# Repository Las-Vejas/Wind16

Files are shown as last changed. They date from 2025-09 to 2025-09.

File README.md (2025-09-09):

# Wind16
A 4x4 macropad, with backlit keys and a fully square design.

## Components

The macropad contains 16 keys, each backlit with an SK6812mini-e led. It is controlled by a Seeed XIAO RP2040 microcontroller using either kmk or qmk software.
The switches will be Gateron Milky Yellows as they feel magnificent. On them there will be white keycaps on which I will make vynil stickers for when I decide on the actions that the keys will be doing.

A lot of people on the HackClub Slack have been against my design, and how I have placed the Xiao. I myself think its a great design choice, that won’t interfere with any other component because, in theory with pin headers commonly being 2 mm tall, I should have enough clearance to fit my components on the top and bottom part of the pcb with just enough to spare so that the RP2040 wouldn’t be touching anything.

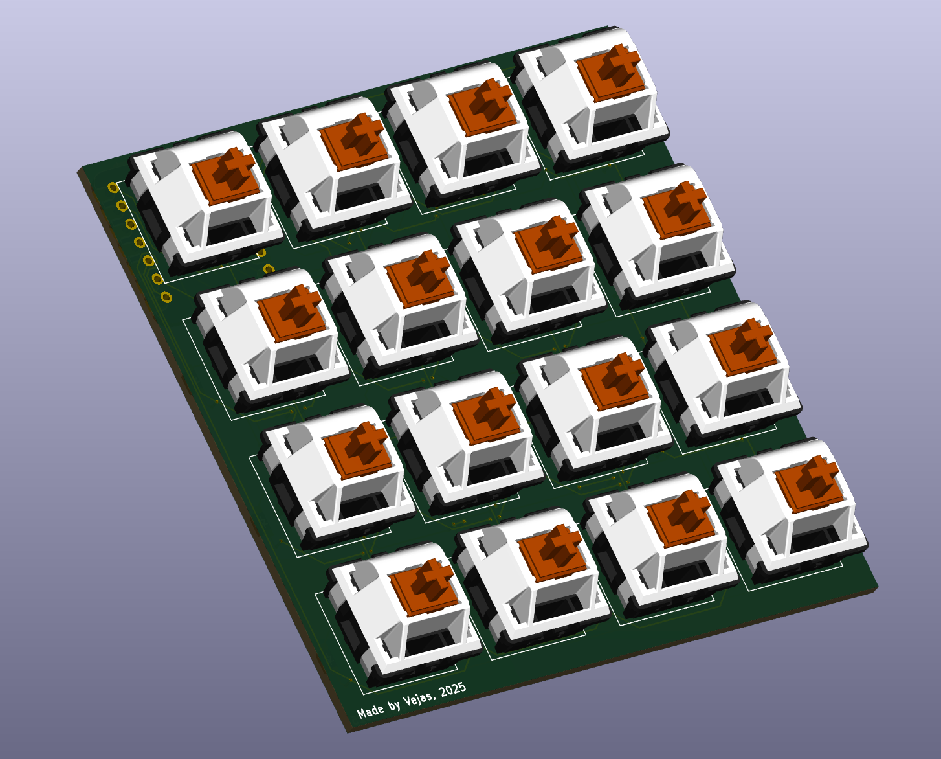
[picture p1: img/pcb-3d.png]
<br>

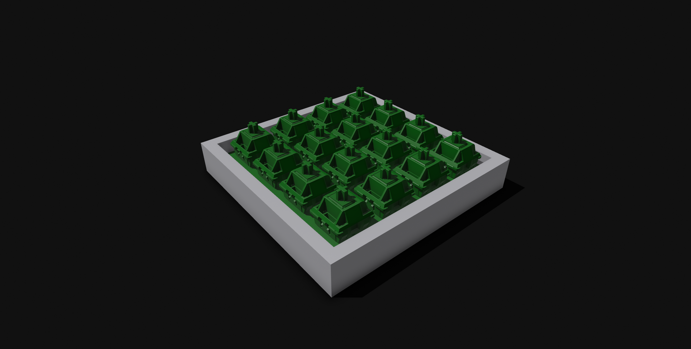
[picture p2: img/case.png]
<br>

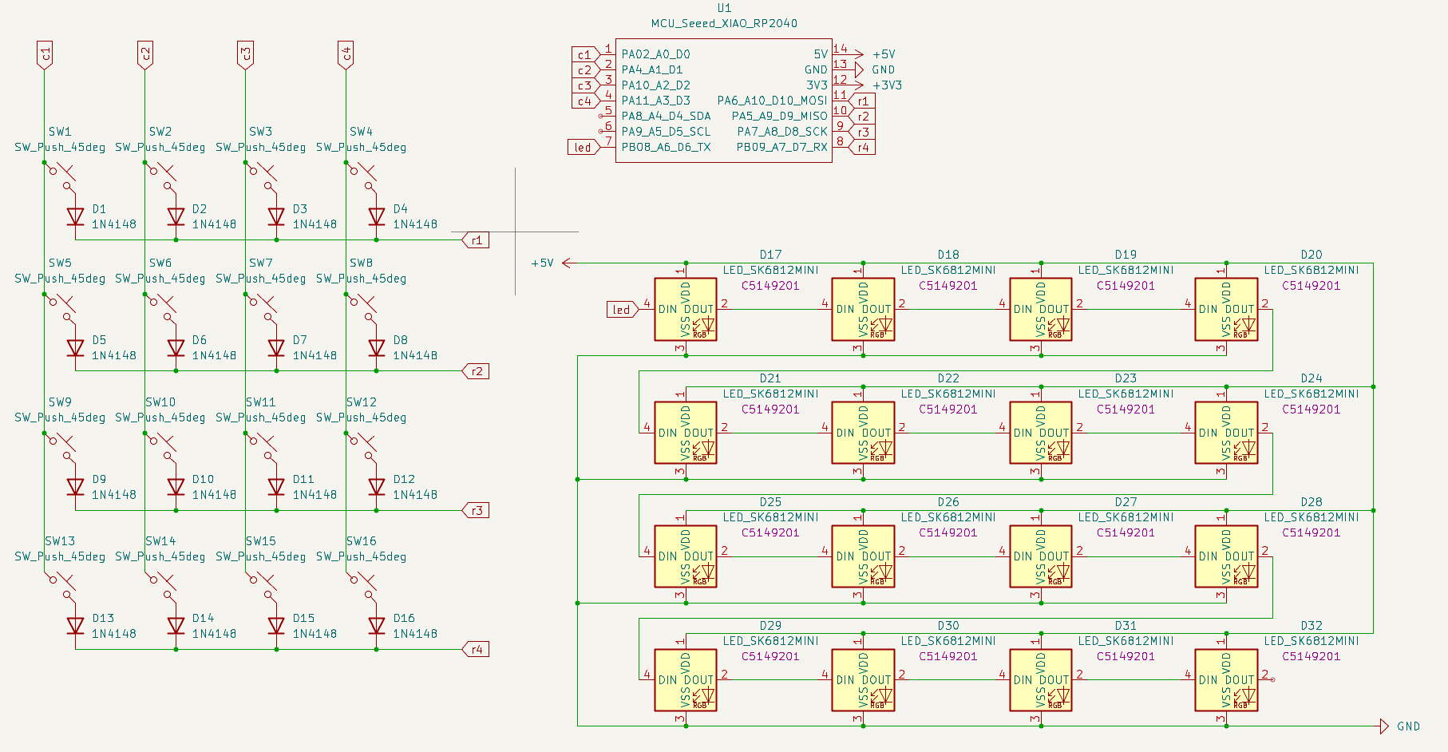
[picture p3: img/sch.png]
<br>

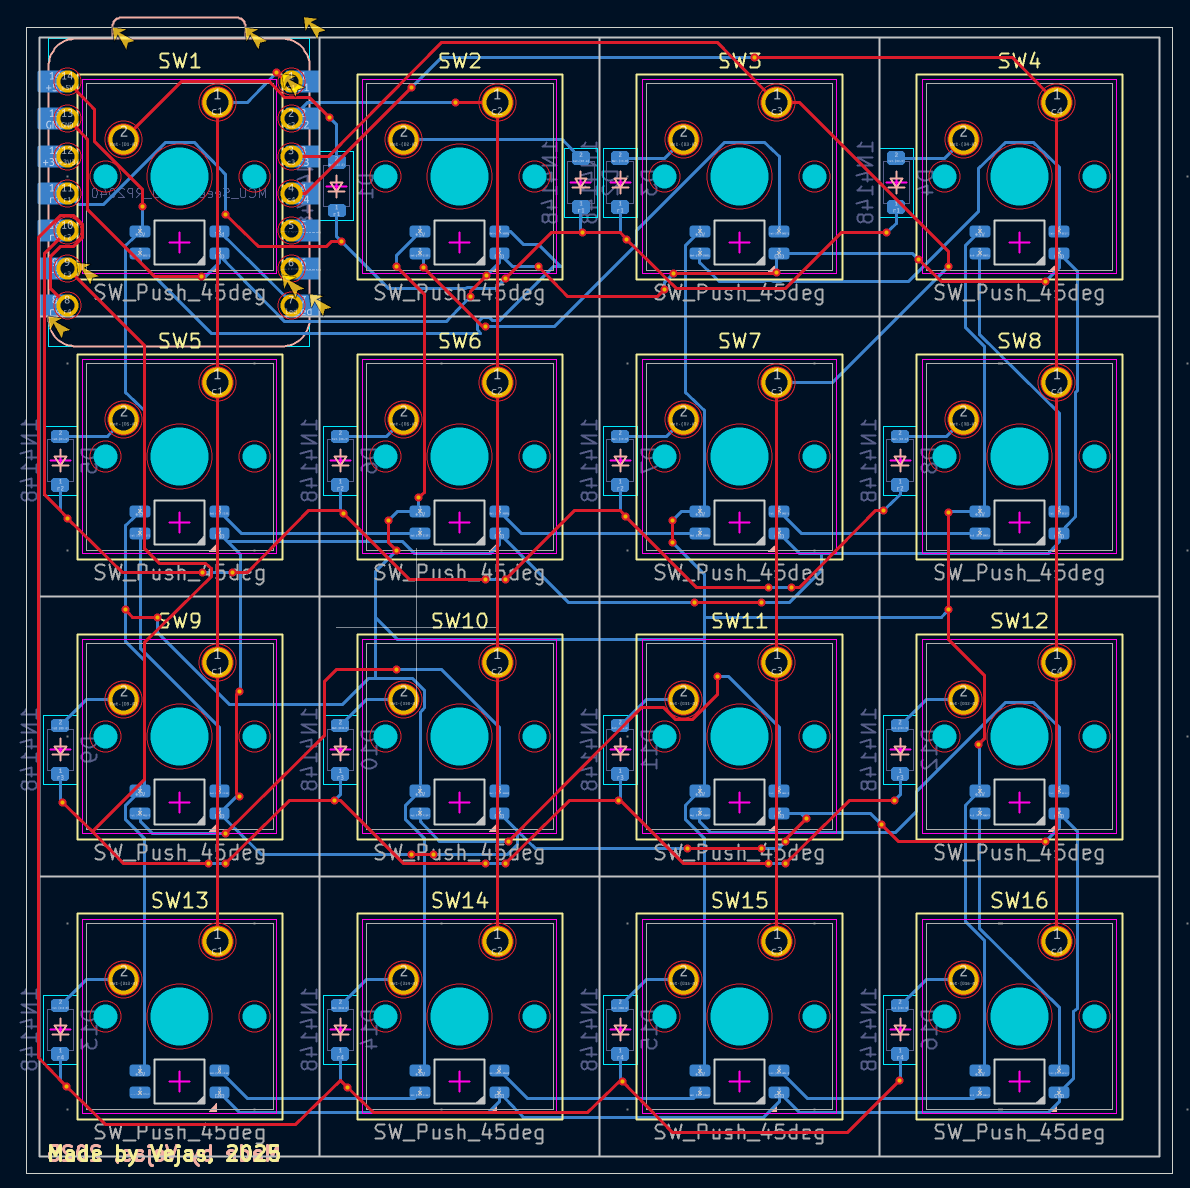
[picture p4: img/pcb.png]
<br>

## BOM

| **Quantity** | **Item** | **Cost** | **Link** |
| --- | --- | --- | --- |
| 16 | Gateron Milky Yellow Switches | $8.32 | [Link](https://fr.aliexpress.com/item/1005006425450443.html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) |
| 16 | Diodes SOD-123 | $1.56 | [Link](https://fr.aliexpress.com/item/1005001994794541.html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) |
| 16 | SK6812mini-e Leds | $3.33 | [Link](https://fr.aliexpress.com/item/1005003056797785.html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) |
| 1 | Seeed Xiao RP2040 | $8.75 | [Link](https://fr.aliexpress.com/item/1005003682505451.html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) |
| 16 | See-through keycaps | $8.28 | [Link](https://fr.aliexpress.com/item/1005002976015114.html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) |
| 1 | 3D printed case | N/A | N/A  | 
| 5 | M2 6mm Screws | $1.70 | [Link](https://www.aliexpress.com/item/1005004531602992.html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) | | 5 | M2 8mm Standoffs | $3.99 | [Link](https://www.aliexpress.com/item/32974970926.html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) |
| 5 | M2 8mm Standoffs | $3.30 | [Link](https://www.aliexpress.com/item/32974970926.html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) |
| 5 | Rubber Bumpers (feet) | $4.01 | [Link](https://fr.aliexpress.com/item/1005006259472984.html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) |

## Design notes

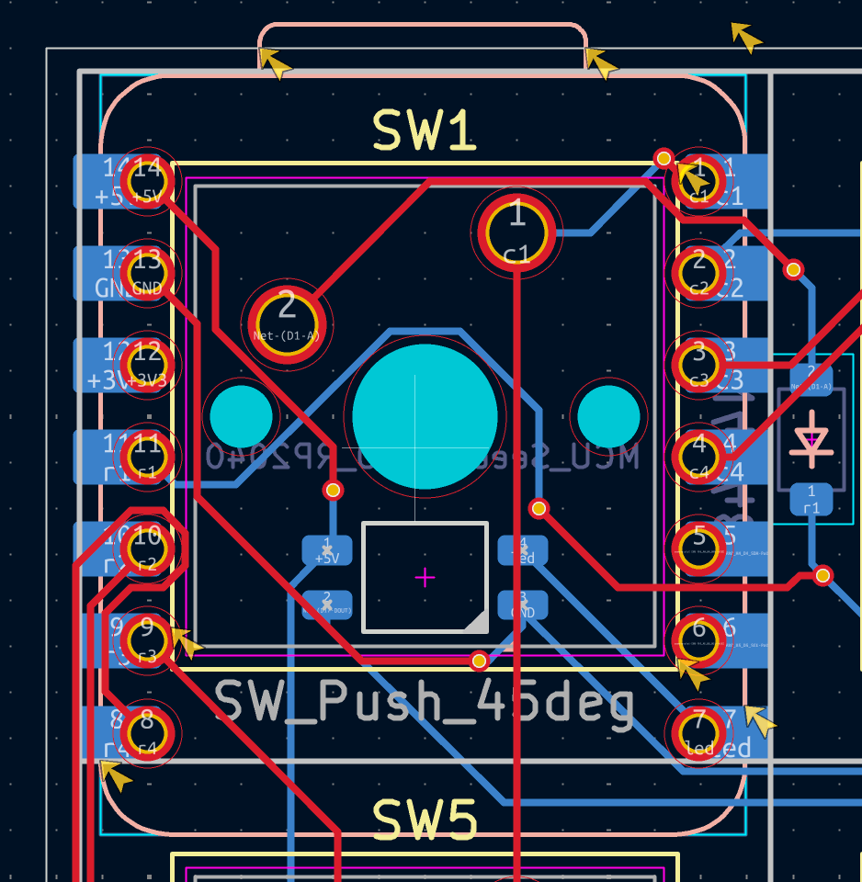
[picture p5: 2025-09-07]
img/xiao.png

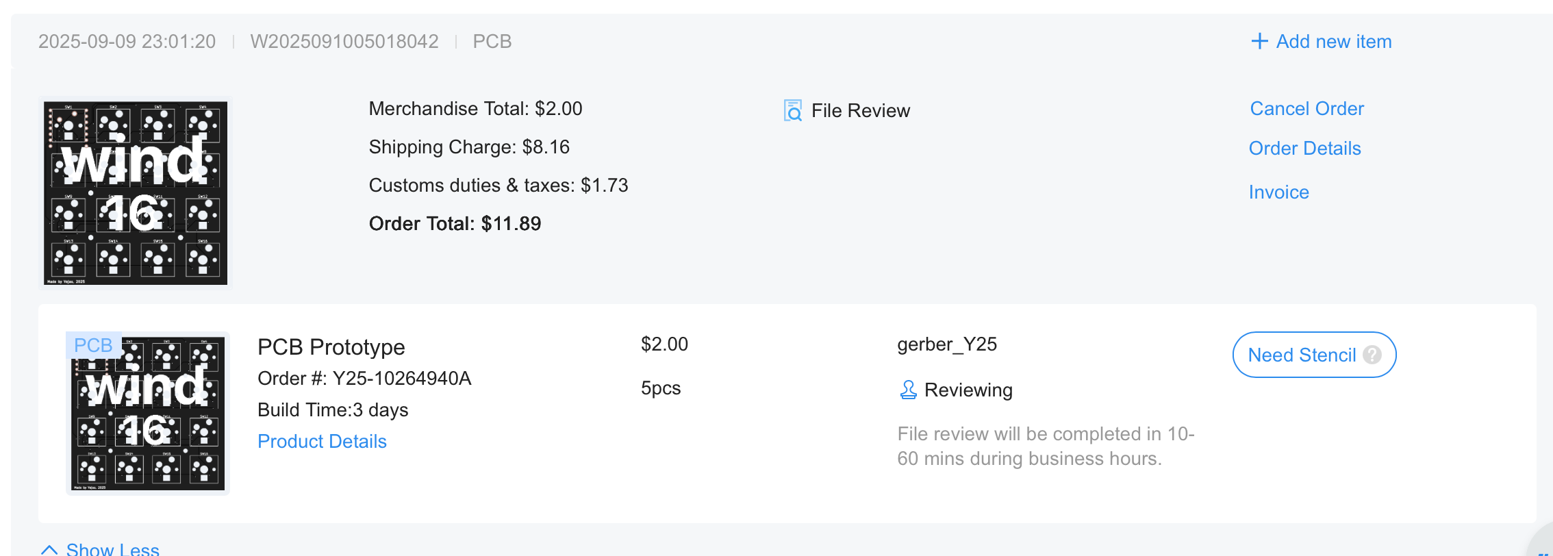
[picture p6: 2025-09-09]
jlccart.png

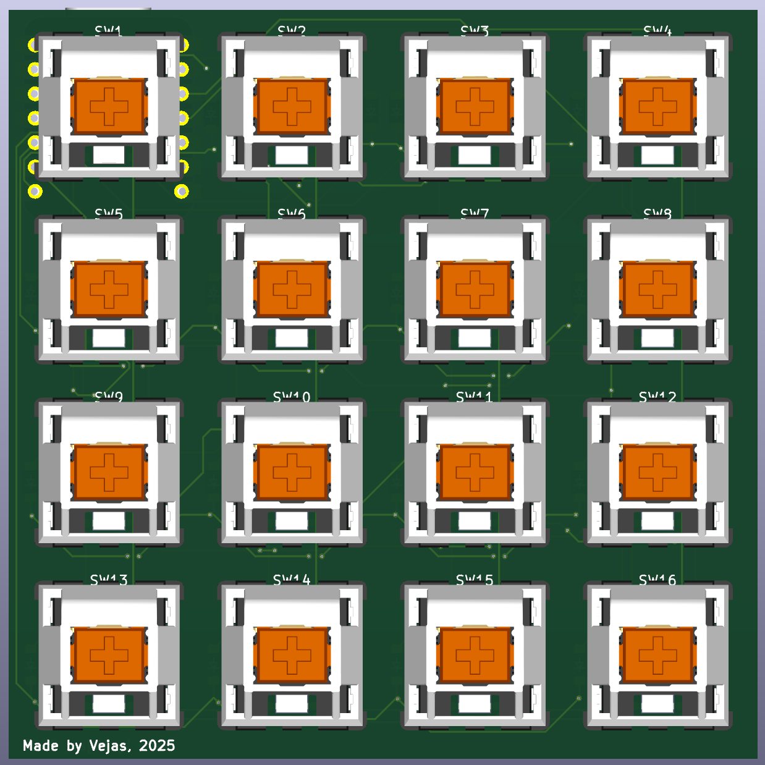
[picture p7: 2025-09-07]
img/pcb-topdown.png

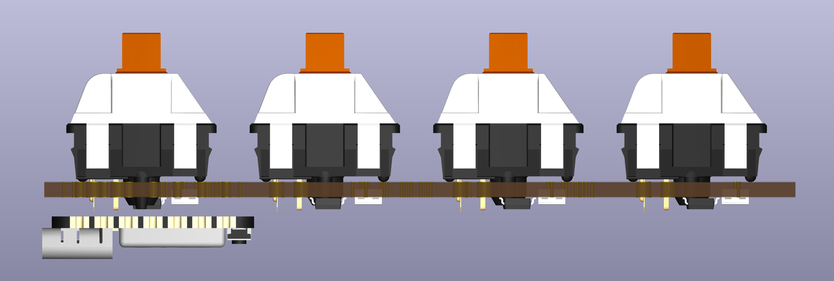
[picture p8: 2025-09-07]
img/SCR-20250907-kzoe.png

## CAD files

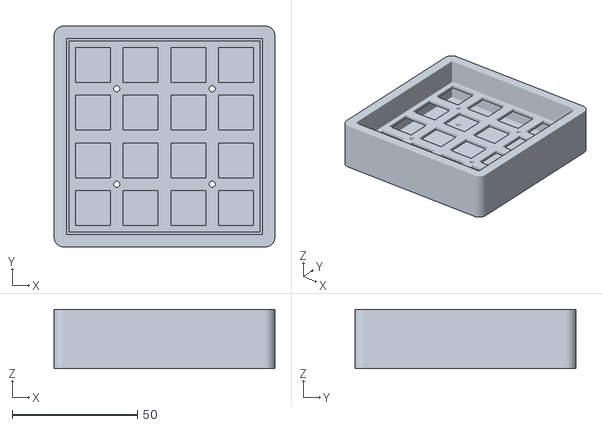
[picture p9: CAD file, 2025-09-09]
3d/case-new.stl
88.2 x 88.2 x 23.6

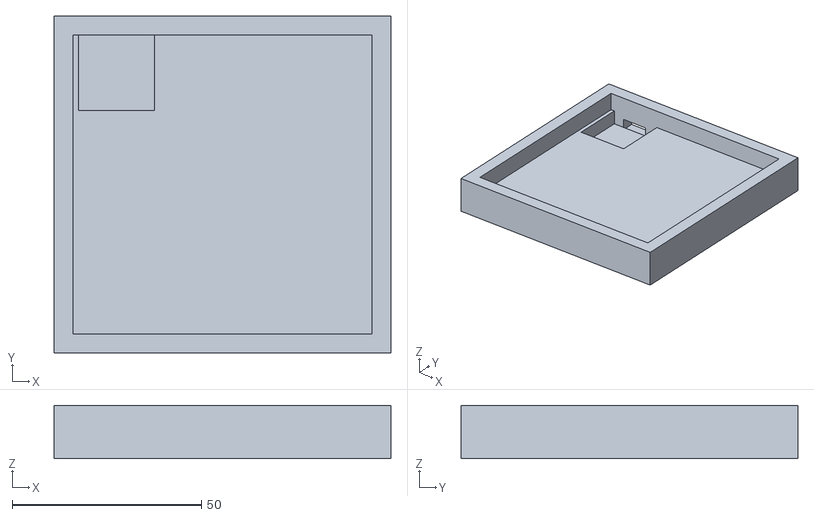
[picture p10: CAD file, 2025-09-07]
3d/wind16-case.stl
89.0 x 89.0 x 14.0

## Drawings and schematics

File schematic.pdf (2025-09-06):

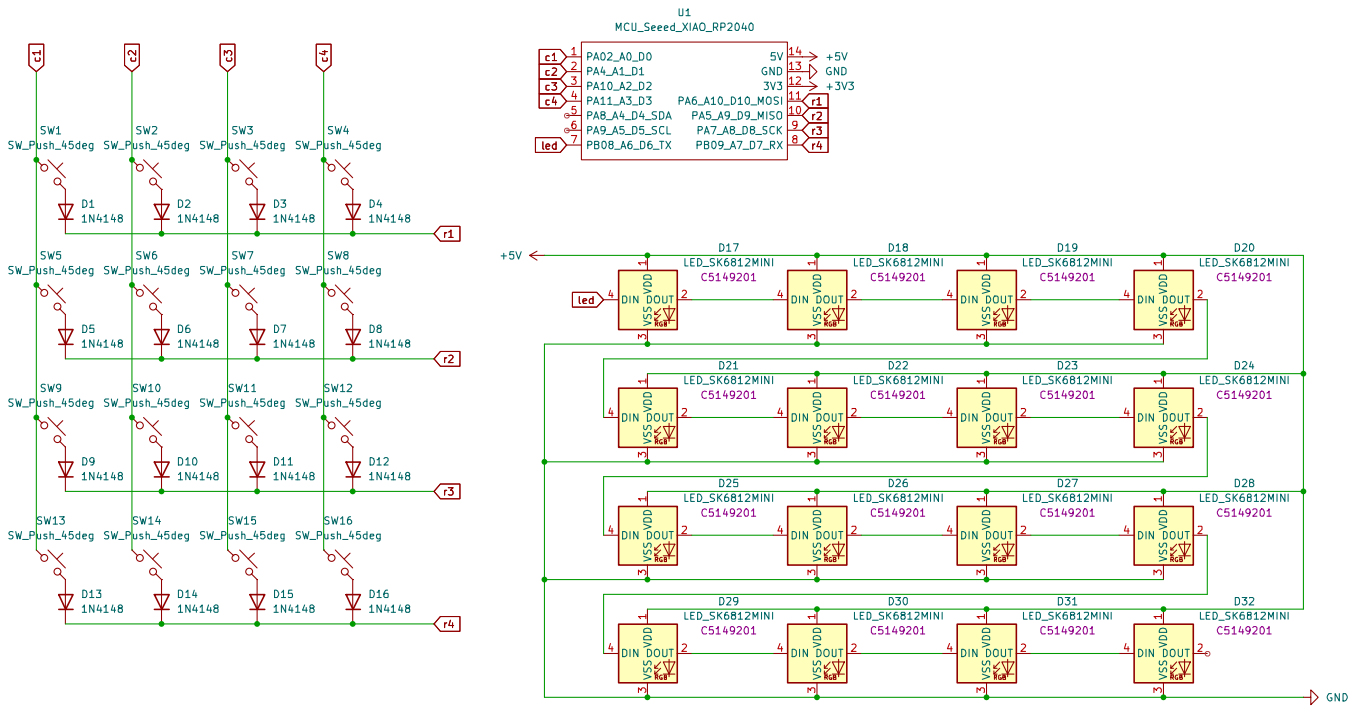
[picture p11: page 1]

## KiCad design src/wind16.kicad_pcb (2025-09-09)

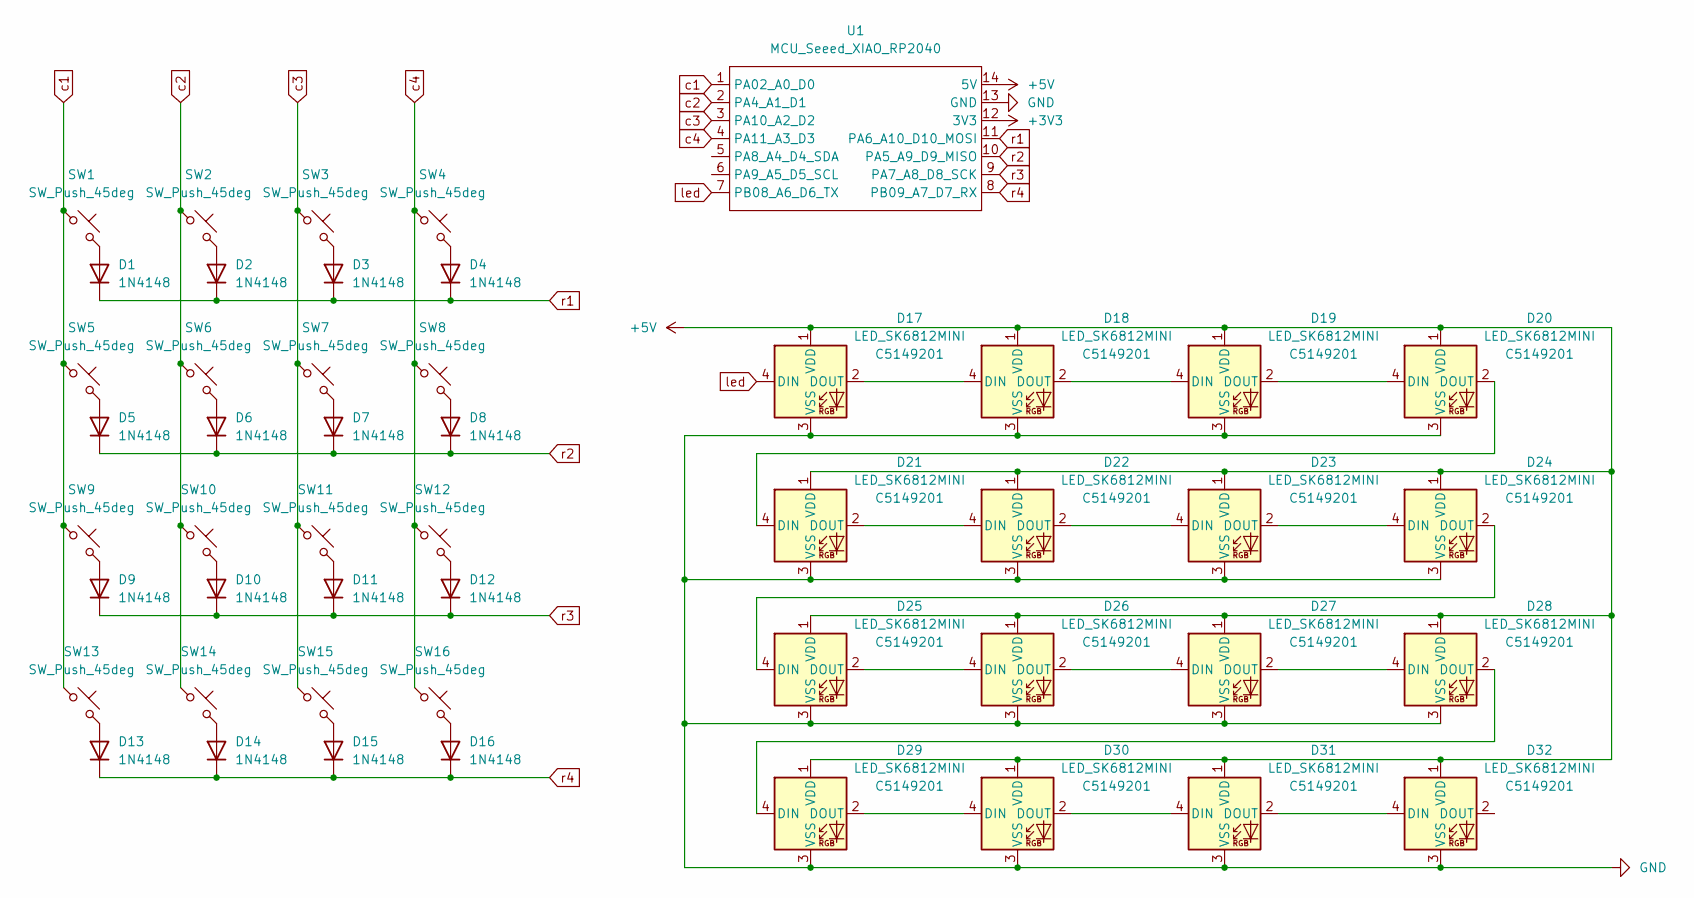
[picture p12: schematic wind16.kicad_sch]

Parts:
D1, D2, D3, D4, D5, D6, D7, D8, D9, D10, D11, D12, D13, D14, D15, D16: 1N4148; Diode_SOD-123
D17, D18, D19, D20, D21, D22, D23, D24, D25, D26, D27, D28, D29, D30, D31, D32: LED_SK6812MINI; LCSC C5149201
SW1: SW_Push_45deg; SW_Cherry_MX_1.00u_PCB
SW2, SW3, SW4, SW5, SW6, SW7, SW8, SW9, SW10, SW11, SW12, SW13, SW14, SW15, SW16: SW_Push_45deg; Hotswap_MX_1.00u
U1: MCU_Seeed_XIAO_RP2040; XIAO-RP2040-DIP

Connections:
+3V3: U1.12 (3V3)
+5V: D17.1 (VDD), D18.1 (VDD), D19.1 (VDD), D20.1 (VDD), D21.1 (VDD), D22.1 (VDD), D23.1 (VDD), D24.1 (VDD), D25.1 (VDD), D26.1 (VDD), D27.1 (VDD), D28.1 (VDD), D29.1 (VDD), D30.1 (VDD), D31.1 (VDD), D32.1 (VDD), U1.14 (5V)
GND: D17.3 (VSS), D18.3 (VSS), D19.3 (VSS), D20.3 (VSS), D21.3 (VSS), D22.3 (VSS), D23.3 (VSS), D24.3 (VSS), D25.3 (VSS), D26.3 (VSS), D27.3 (VSS), D28.3 (VSS), D29.3 (VSS), D30.3 (VSS), D31.3 (VSS), D32.3 (VSS), U1.13 (GND)
unnamed: D1.2 (A), SW1.2
unnamed: D2.2 (A), SW2.2
unnamed: D3.2 (A), SW3.2
unnamed: D4.2 (A), SW4.2
unnamed: D5.2 (A), SW5.2
unnamed: D6.2 (A), SW6.2
unnamed: D7.2 (A), SW7.2
unnamed: D8.2 (A), SW8.2
unnamed: D9.2 (A), SW9.2
unnamed: D10.2 (A), SW10.2
unnamed: D11.2 (A), SW11.2
unnamed: D12.2 (A), SW12.2
unnamed: D13.2 (A), SW13.2
unnamed: D14.2 (A), SW14.2
unnamed: D15.2 (A), SW15.2
unnamed: D16.2 (A), SW16.2
unnamed: D17.2 (DOUT), D18.4 (DIN)
unnamed: D18.2 (DOUT), D19.4 (DIN)
unnamed: D19.2 (DOUT), D20.4 (DIN)
unnamed: D20.2 (DOUT), D21.4 (DIN)
unnamed: D21.2 (DOUT), D22.4 (DIN)
unnamed: D22.2 (DOUT), D23.4 (DIN)
unnamed: D23.2 (DOUT), D24.4 (DIN)
unnamed: D24.2 (DOUT), D25.4 (DIN)
unnamed: D25.2 (DOUT), D26.4 (DIN)
unnamed: D26.2 (DOUT), D27.4 (DIN)
unnamed: D27.2 (DOUT), D28.4 (DIN)
unnamed: D28.2 (DOUT), D29.4 (DIN)
unnamed: D29.2 (DOUT), D30.4 (DIN)
unnamed: D30.2 (DOUT), D31.4 (DIN)
unnamed: D31.2 (DOUT), D32.4 (DIN)
c1: SW1.1, SW5.1, SW9.1, SW13.1, U1.1 (PA02_A0_D0)
c2: SW2.1, SW6.1, SW10.1, SW14.1, U1.2 (PA4_A1_D1)
c3: SW3.1, SW7.1, SW11.1, SW15.1, U1.3 (PA10_A2_D2)
c4: SW4.1, SW8.1, SW12.1, SW16.1, U1.4 (PA11_A3_D3)
led: D17.4 (DIN), U1.7 (PB08_A6_D6_TX)
r1: D1.1 (K), D2.1 (K), D3.1 (K), D4.1 (K), U1.11 (PA6_A10_D10_MOSI)
r2: D5.1 (K), D6.1 (K), D7.1 (K), D8.1 (K), U1.10 (PA5_A9_D9_MISO)
r3: D9.1 (K), D10.1 (K), D11.1 (K), D12.1 (K), U1.9 (PA7_A8_D8_SCK)
r4: D13.1 (K), D14.1 (K), D15.1 (K), D16.1 (K), U1.8 (PB09_A7_D7_RX)

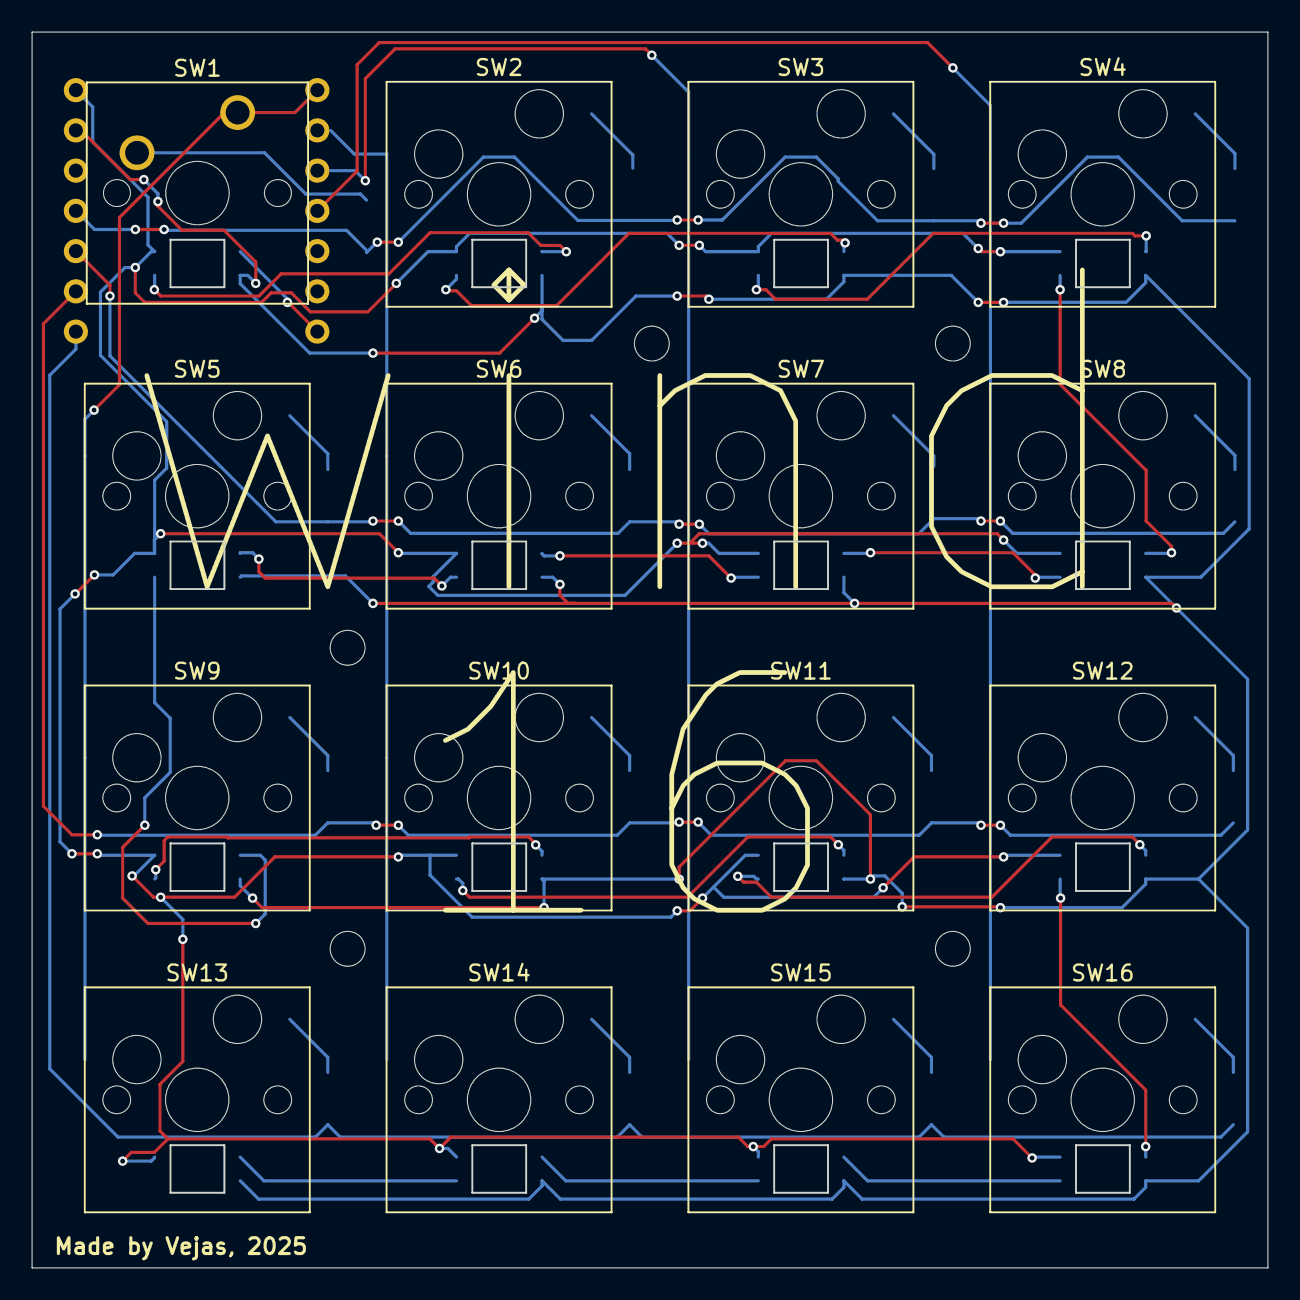
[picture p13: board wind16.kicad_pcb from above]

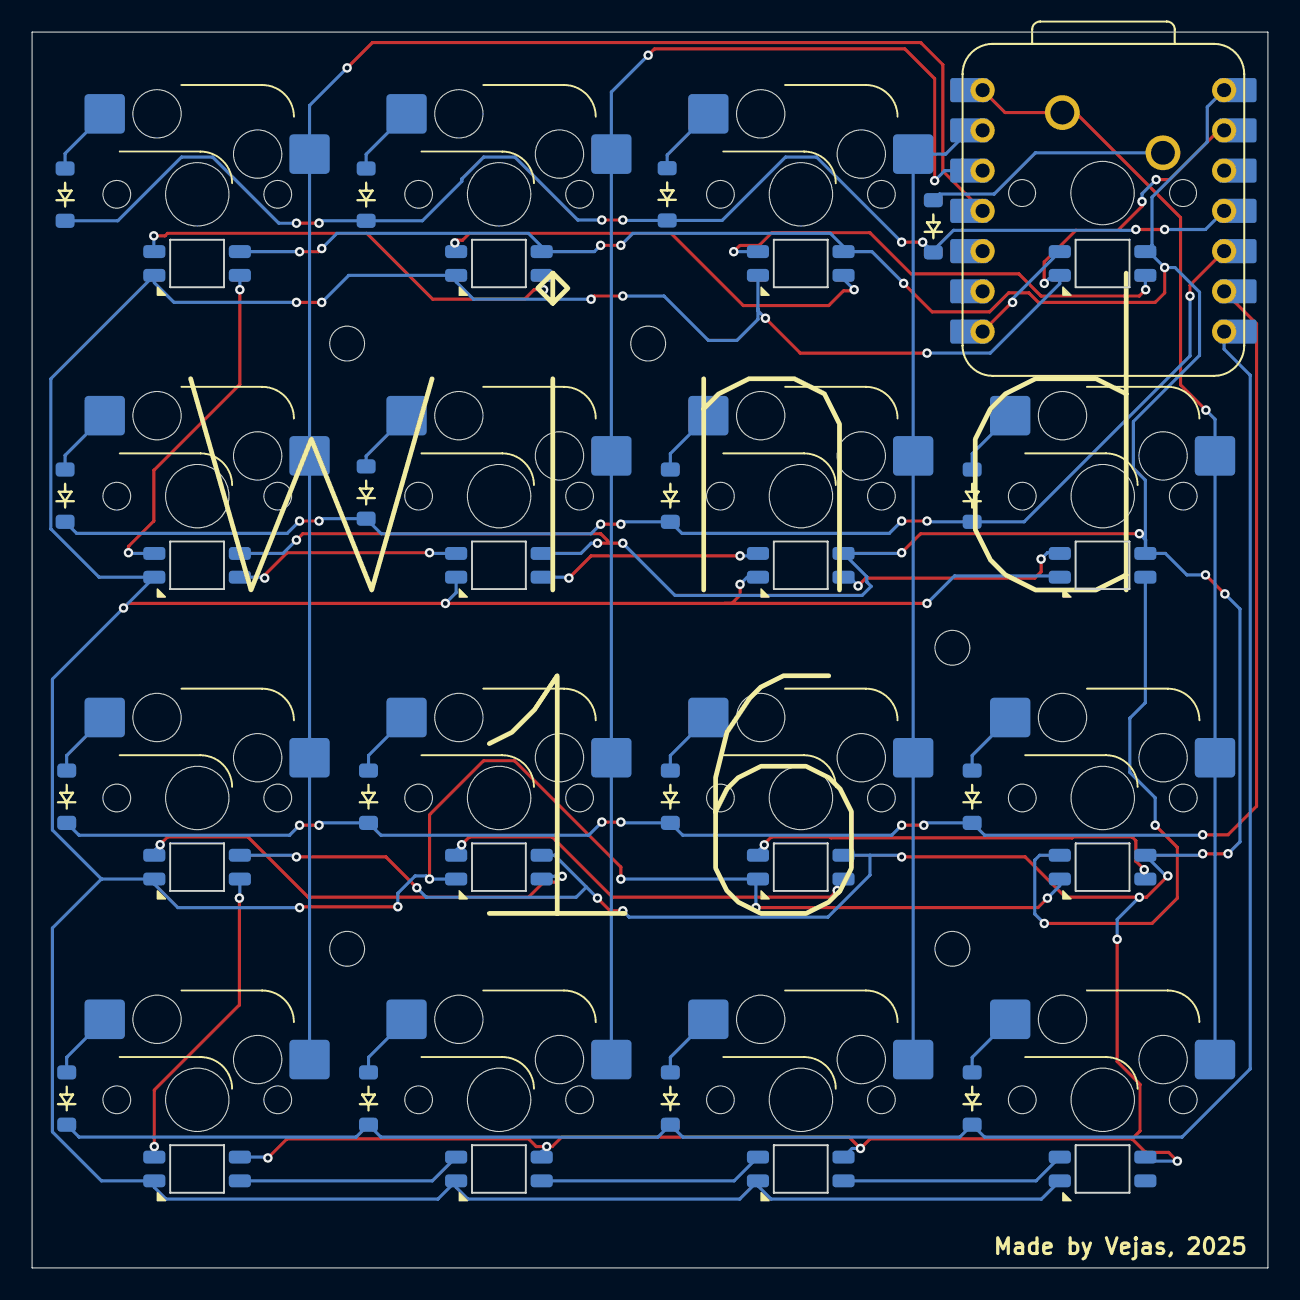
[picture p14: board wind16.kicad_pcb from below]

Board: 2 copper layers, 78.0 x 78.0 mm, 49 parts (33 on the bottom side), 42 nets.

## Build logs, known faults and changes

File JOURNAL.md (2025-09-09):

---
Title: “Wind16"
Author: “@lasvejas"
Description: “A 16 key macropad laid out in a 4x4 layout with rgb lighting under each key."
Created On (d/m/y): “6/8/2025"
---

## September 6th: Starting and in theory finishing.

I started this project and decided to make a 16 key macropad. I layed it out in a 4x4 layout. This time I wanted to try out something new and cram the rp2040 on the back side opposite a key switch.

I am taking this approach so that my macropad would be a perfect square, and because I got tired of the big ugly lip everyone has at the top.

I put the MCU behind the first switch so the usb port would be in a nice place.
I used sod diodes because they are smaller (I know ironic huh) but also I won’t have a bunch of holes I have to worry about, and clearance under the rp2040.

I will be using some type of MX switch.

## September 7th: Fighting people about my design + 3D Case

A lot of people on the HackClub Slack have been skeptical on how I have placed the Xiao. 
I myself think its a great design choice, that won’t interfere with any other component because, in theory with pin headers commonly being 2 mm tall, I should have enough clearance to fit my components on the top and bottom part of the pcb with just enough to spare so that the RP2040 wouldn’t be touching anything.

| PCB with populated switches | Clearance (Pin headers accounted for)|
|---|---|
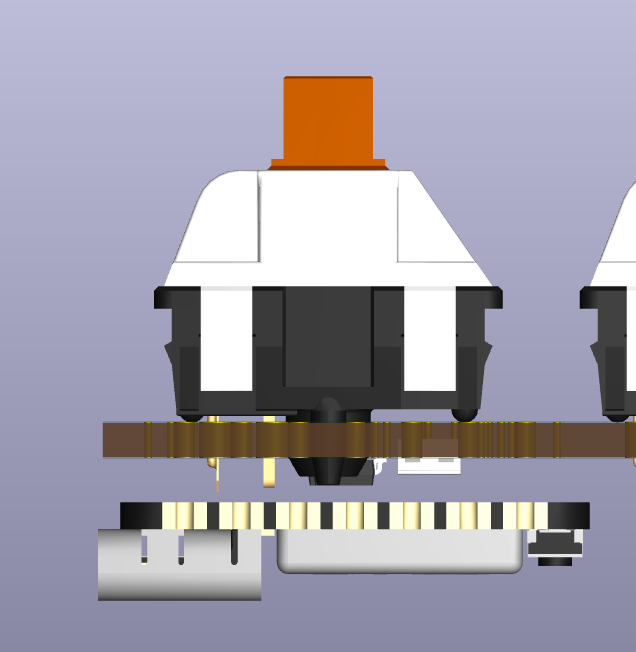
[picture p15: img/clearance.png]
Clearance of rp2040
| PCB with switches<br> | <br>  |

### 3D Case

I have also added a case to house the bottom pcb, but I do not think a top plate or case is really necessary at the moment.

3d printed case<br>

I also decided that I will be using white keycaps for the leds to shine on. 

# September 8 + 9 - New case + change of mind

I watched a guide on how to make a case for your keyboard by ScottoKeebs (which is an amazing video).
I then made a case in Shapr3d trying to incorporate some M2.5 screws that I have left over from another build, but I will have to buy some standoffs for this keyboard.

This also included me adding holes in my pcb for screws.

- 23:47
	- I had the bright idea of changing all my switches (except the top left) to hotswappable ones...
	- This ensued a lot of rewiring and adjustments.
	- I also changed the m2.5 screws to m2 screws because they just fit better.

- 05:48
	- Finished my overhaul, with like 5 hrs of sleep in that. 15 of 16 switches are now Hotswappable, with the very first switch getting constrained by the Xiao.
    - Added 5 mounting holes in the pcb but idk how its gonna be mounted with my plate, because there will be standoffs resting below… so I guess we’ll see abt that but I can always tweak the case design and reprint it in my local maker space.

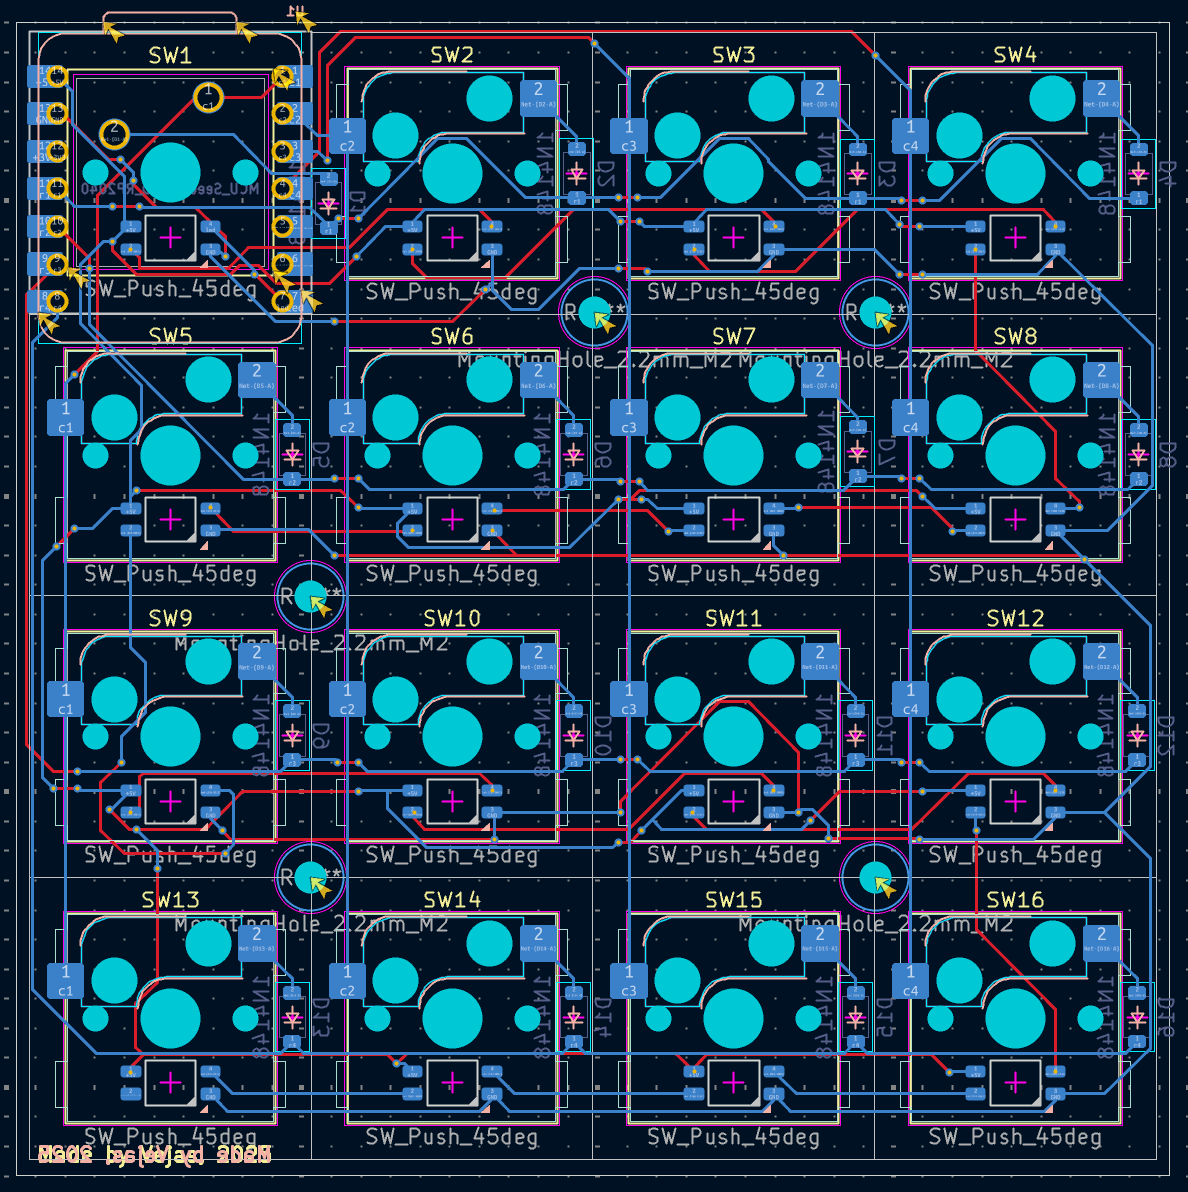
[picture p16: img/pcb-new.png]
PCB overhaul
    - <br>
- 06:18
	- Exporting all files, getting ready for submission.
- 06:57
  	- Very last changes, Gerbers, silkscreen, etc.	

I think this is the end for this project unless I need to change something or I’ll write when I do the software.
(My English teacher would probably have a stroke reading this :skull:)

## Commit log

2025-09-06 added journal
    [GNDPAD.kicad_pcb, GNDPAD.kicad_sch]
2025-09-07 stuff 1.2
    [wind16-case.stl, wind16.kicad_pcb, wind16.kicad_sch]
2025-09-07 added bom
2025-09-09 loads of shit 1.3
    [case-new.stl, wind16.kicad_pcb, wind16.kicad_sch]
2025-09-09 update bom
2025-09-09 gerbers, jlc, small changes
    [wind16.kicad_pcb]
